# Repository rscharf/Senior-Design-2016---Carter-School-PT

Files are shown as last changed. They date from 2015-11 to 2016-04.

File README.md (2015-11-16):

# Senior Design 2016 - Carter School Physical Therapy
<br />
<center>

<br />
###BU ECE Senior Design Project
</center>
Creating an interactive wall-mounted display that helps with the physical therapy
program and individual student goals at the Carter School in Boston, MA.  The system consists of puzzle piece-shaped panels with LED numbers that light up when students move past each panel's active IR sensor.  With this system, we will help to foster a desire in the students to achieve new milestones in their own mobility as well as a deeper understanding of cause-and-effect and number sense.

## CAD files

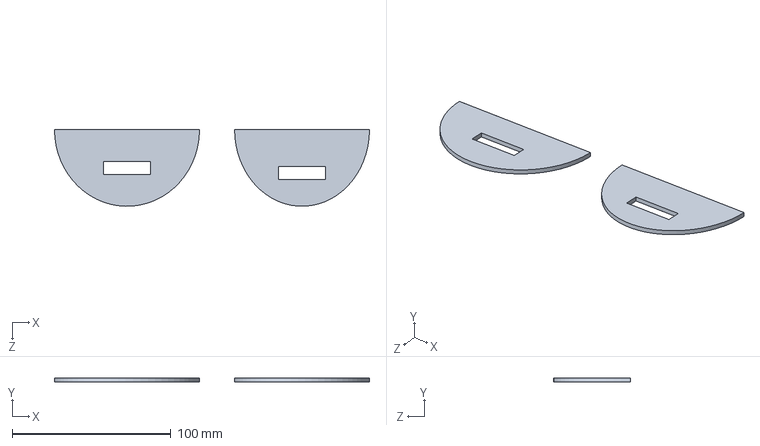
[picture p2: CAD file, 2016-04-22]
Solidworks/endbits.SLDPRT
198.7 x 2.54 x 48.3 mm

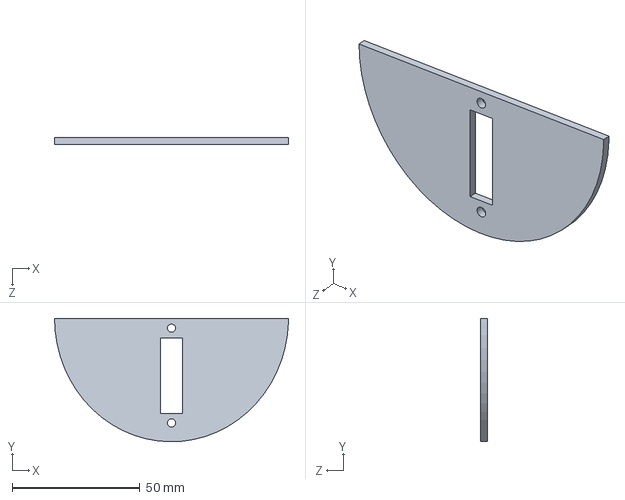
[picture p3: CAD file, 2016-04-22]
Solidworks/Sensor-end(acrylic).SLDPRT
91.4 x 48.3 x 2.54 mm

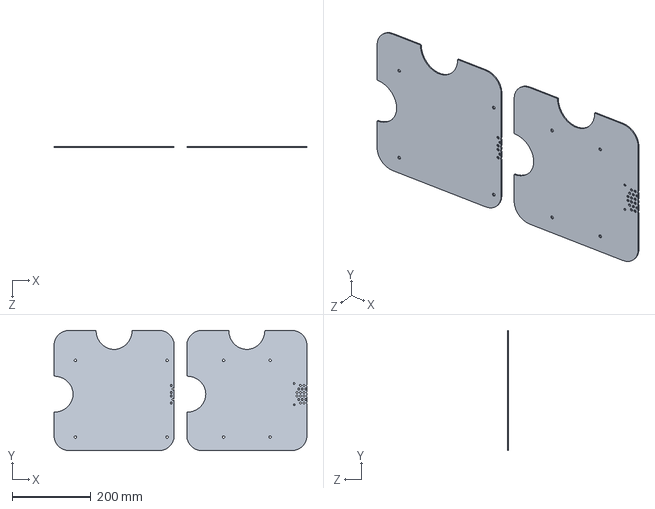
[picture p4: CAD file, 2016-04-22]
Solidworks/acrylic-screws.SLDPRT
641.3 x 304.8 x 2.54 mm

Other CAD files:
Solidworks/2fixed.SLDPRT
Solidworks/final.SLDPRT
Solidworks/sensor-end(film).SLDPRT
Solidworks/polyeth.SLDPRT
Solidworks/polyeth-outline.SLDDRW
Solidworks/sensor-end(film).SLDDRW

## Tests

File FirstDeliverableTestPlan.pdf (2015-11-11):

1

# Memo

To: | Professor Pisano, Professor Alshaykh, Professor Kia, Nithin Sivadas, Yue Zhang, Asher McGuffin
From: | Reva Scharf, Jian Tan, Jesse Leinbach, Austin Schiller, Maya Saint Germain, and Aidar Aidymbekov
Team: | 21
Date: | 11/10/2015
Subject: | Carter School Sensory Walk – First Deliverable Testing

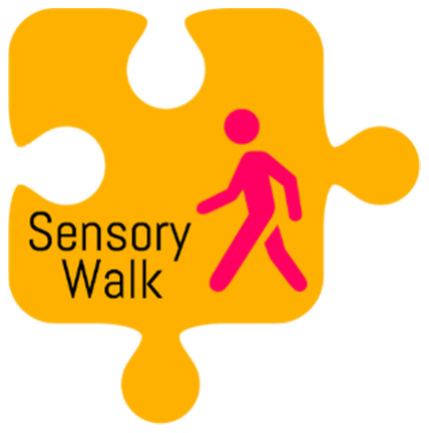
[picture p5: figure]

### 1.0 Panel Design: Hardware and Software

### 1.1 Description and Goal

As a proof of concept, we have a prototype of our sensor driven LEDs. The setup of each individual panel consists of one MSP430, one active IR sensor, and one LED driver circuit. The IR sensor emits IR, detects the reflected IR, and outputs an analog signal proportional to the intensity of the reflected IR detected. This analog signal is connected to a pulldown resistor as well as to a capacitor to ground in order to mitigate high frequency noise. The MSP430 then converts it into a digital signal with the use of an analog-to-digital converter (ADC) and averages the values in groups of five to further filter out noise. This averaged value is compared to a set threshold value, and if it is above the threshold, the on-board LED and P1.2 are set to high. P1.2 is connected to the base of our power BJT. This effectively turns it on, sending current to the emitter and powering a set of LEDs.
This system is the first iteration of the basic panel in our final modular design, which will consist of a group of similar panels that communicate with one another in order to detect movement along the school’s hallway. The communication between the MSP430s is implemented by connecting the two microcontrollers at their respective P1.5’s. Panel 0 sets a flag once it has been triggered. This flag is checked by Panel 1 on every cycle and it will only become active once Sensor 0 has been activated. This will help to prevent people or objects from interfering with the physical therapy session.

# Senior Design

## ENG EC 463

2

### 1.2 Procedure

Ensure both MSP430s are plugged in and power supply is supplying 5 volts. Connect the sensor output to an oscilloscope in order to show its effective range. Demonstrate two modes by loading each mode and then demonstrating. The first mode will allow both LEDs to turn on when an object is detected and off when nothing is detected. The second mode will show that the LEDs connected to Sensor 1 will not turn on until those of Sensor 0 turn on. Walk past the sensors, starting with sensor 0. Reset the system by pressing the on-board button (P1.3) of Sensor 0. Walk past Sensor 1 first, then Sensor 0, and then back to Sensor 1.

### 1.3 Verifiable Result

The MSP430 will constantly collect data from the sensor, convert it to a digital signal, store and average groups of five, and compare the average to a threshold. We can demonstrate the success of this process if the LEDs are activated by objects entering the sensor’s view. The distance from the person activating the system to the sensor will be on the order of 3 feet. This distance is more than acceptable to detect a student passing the sensor in a hallway. As the person gets closer, the oscilloscope will show how the sensor outputs a higher voltage. We will also show that once out of range completely, the voltage drops to zero. In the first mode, note that objects in range of 3 feet of either sensor will turn on their respective LEDs. If no objects are in range, the LEDs will turn off. In the second mode, note that Panel 1 is only activated after Panel 0 has been activated. Also note that pressing the on-board button (P1.3) of Panel 1 will reset only Panel 1, while pressing the button on Panel 0 resets both.

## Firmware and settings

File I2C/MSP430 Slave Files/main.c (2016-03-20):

/*** USCI slave library ********************************************************

In this file the usage of the USCI I2C slave code is shown. 
This code uses callback functions as an interface for the user. For each 
byte that is received or is to be transmitted the corresponding callback 
function is called by the USCI I2C function set.


PWM HELP:
http://coder-tronics.com/msp430-timer-pwm-tutorial/

Uli Kretzschmar
MSP430 Systems
Freising
*******************************************************************************/
#include "msp430.h"

#include "TI_USCI_I2C_slave.h"

void receive_cb(unsigned char receive);
void transmit_cb(unsigned char volatile *receive);
void set_address(unsigned char new_address);
void start_cb();

unsigned char set_add_flag = 0;
unsigned char TXData = 0 ;
unsigned char RXData = 0 ;
unsigned int byte_num = 0;
unsigned int state = 0;
unsigned char incomingData = 0;
unsigned char sensor_flag = 0;
unsigned int button_flag = 0;
unsigned int new_duty_cycle = 0;
//#define RESET_BUTT 8
/*** Global Variable ***/
int IncDec_PWM = 1;
// ADC variables
// Global variables that store the results (read from the debugger)
 volatile int latest_result;   // most recent result is stored in latest_result
 //volatile unsigned long conversion_count=0; //total number of conversions done
 volatile int adc_vals_before_ave = 0;
 volatile int adc_average = 0;
 volatile int adc_average_add = 0;
 volatile int adc_vals_array[5];
 volatile unsigned char last_button;
 volatile unsigned char last_button2;
 int blink_interval = 0;
 int blink_counter = 0;



// Declare variables in the information memory
#pragma DATA_SECTION(assigned_address,".infoD");
volatile const char assigned_address = 0x7f;

void main(void)
{

   TI_USCI_I2C_slaveinit(start_cb, transmit_cb, receive_cb, assigned_address); // init the slave
  _EINT();
  BCSCTL1 = CALBC1_16MHZ; 
  DCOCTL = CALDCO_16MHZ; //16 MHz calibration for clock
  init_adc();
  init_wdt();


  	P1DIR |= RED;                             // Set RED to output direction
    P1DIR |= BJT_OUT;
    P1DIR &= ~BUTTON;
    P1OUT &= ~BJT_OUT;

    P1OUT |= BUTTON;
    P1REN |= BUTTON;

    	/*** GPIO Set-Up ***/
        P1SEL |= BJT_OUT;					// BJT selected Timer0_A Out1 output

    	/*** Timer0_A Set-Up ***/
        TA0CCR0 |= 100;					// PWM period
        TA0CCR1 |= 0;					// TA0CCR1 PWM duty cycle
        TA0CCTL1 |= OUTMOD_7;			// TA0CCR1 output mode = reset/set
        TA0CTL |= TASSEL_2 + MC_1;		// SMCLK, Up Mode (Counts to TA0CCR0)


  _bis_SR_register(GIE+LPM0_bits);
}

void start_cb(){
  RXData = 0;
}

// Receive callback function. Values received are interpreted based on current state
// RPi should pass first the state and then the data and MSP will act accordingly
void receive_cb(unsigned char receive){
  byte_num++; //increases by 2 for every time this function is called
  if (byte_num == 2){ //first byte passed = state
	  state = receive;
  }
  else if (byte_num == 4){ //second byte passed is data (data is now stored in variable receive)
	  byte_num = 0;
  }

  if (byte_num == 0) //if data has just been received
  {
   switch(state) // Save new address to flash memory
   {
   	   case 0: //idle state
   		   P1OUT &= ~RED; //turn off on board LED?
   		   //P1OUT &= ~BJT_OUT; //turn off BJT LEDs
   		   TA0CCR1 = receive;
   		   break;
   	   case 1: // setting new address
   		   eraseD(); //Erase Data in D
   		   writeDword(receive, (char *) &assigned_address);//SET NEW ADDRESS in flash mem
   		   UCB0I2COA = assigned_address; // Set slave address register to address stored in flash mem
   		   break;
   	   case 2: //panel active and listening for sensor trigger
   		   break; //data received doesn't matter
   	   case 3: //idle state with lights activated - turn on LEDs
   		   //pi
   		   TA0CCR1 = receive; //set new duty cycle to value of brightness preference
   		   P1OUT |= BJT_OUT; //Turn on BJT LEDs
   		   P1OUT |= RED; //Turn on on-board LED
   		   sensor_flag = 0;
   		   break;
   	   case 4:
   		   break; //data received doesn't matter
   	   default:
   		   break;
   }

    }

}

void transmit_cb(unsigned char volatile *byte){
	 switch(state) // Save new address to flash memory
	   {
	   	   case 0: //idle state
	   		   *byte = 0;
	   		   P1OUT &= ~BJT_OUT; //Turn off BJT LEDs
	   		   P1OUT &= ~RED; //Turn off on-board LED
	   		   break;
	   	   case 1: // setting new address
	   		   *byte = assigned_address; //Send slave's address to master (retreived from flash mem)
	   		   state = 0; //reset to Idle state after new address is sent to master
	   		   break;
	   	   case 2: //panel active and listening for sensor trigger
	   		   if ((sensor_flag == 1))
	   		   {
    			*byte = 1;
    			sensor_flag = 0;
    			button_flag = 0;
	   			//state = 3; //Dont enter state 3 until told by RPI..later
	   		   }
	   		   else *byte = 0;
	   		   break; //data received doesn't matter
	   	   case 3: //idle state with lights activated, no action in transmit necessary
	   		   *byte = 0;
	   		   break;
	   	   default:
	   		   *byte = 0;
	   		   break;
	   }
}

/*
 * The ADC handler is invoked when a conversion is complete.
 * Its action here is to simply store the result in memory.
 */
 void interrupt adc_handler(){
	 latest_result=ADC10MEM;   // store the answer
 }
 ISR_VECTOR(adc_handler, ".int05")




// ===== Watchdog Timer Interrupt Handler =====
interrupt void WDT_interval_handler(){

{
						ADC10CTL0 |= ADC10SC;  // trigger a conversion
						//Reset button. Should this only be accessible from state 2/3?
						//button handling - for now this button acts as a sensor+
						unsigned char b;
						b= (P1IN & BUTTON);  // read the BUTTON bit
						if (last_button && (b==0))
						{ // has the button bit gone from high to low
						  //turn off LEDs and go back to idle state
							//P1OUT ^= RED;
							P1OUT &= ~RED; //turn off on board LED?
							P1OUT &= ~BJT_OUT; //turn off BJT LEDs
							button_flag = 1;
							state = 0;
						}
						last_button=b;    // remember button reading for next time.


						int j;
						for (j=0; j<5; j++)
						{
							adc_average_add = adc_average_add + adc_vals_array[j];
						}
						adc_average = adc_average_add/5;
						adc_average_add = 0;

						if ((adc_average > IR_THRESHOLD) && (state == 2))
						{
							//P1OUT |= RED;
							sensor_flag = 1; //indicate sensor trigger
						}

						if (adc_vals_before_ave == 5)
						{
							adc_vals_before_ave = 0;
						}
						else
						{
							adc_vals_array[adc_vals_before_ave] = latest_result;
							adc_vals_before_ave++;
						}

	 	 }

}

ISR_VECTOR(WDT_interval_handler, ".int10")

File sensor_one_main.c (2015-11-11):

/* 10-30-13
 * This is an example of using the ADC to convert a single
 * analog input. The external input is to ADC10 channel A4.
 * This version triggers a conversion with regular WDT interrupts and
 * uses the ADC10 interrupt to copy the converted value to a variable in memory.
*/

#include "msp430g2553.h"

// Define bit masks for ADC pin and channel used as P1.4
#define ADC_INPUT_BIT_MASK 0x10
#define ADC_INCH INCH_4
#define BJT_OUT	4
#define COM_IN 0x20
#define RESET_BUTT 8

#define IR_THRESHOLD	70

 /* declarations of functions defined later */
 void init_adc(void);
 void init_wdt(void);

// =======ADC Initialization and Interrupt Handler========

// Global variables that store the results (read from the debugger)
 volatile int latest_result;   // most recent result is stored in latest_result
 //volatile unsigned long conversion_count=0; //total number of conversions done
 volatile int adc_vals_before_ave = 0;
 volatile int adc_average = 0;
 volatile int adc_average_add = 0;
 volatile int adc_vals_array[5];
 volatile unsigned char last_button;

/*
 * The ADC handler is invoked when a conversion is complete.
 * Its action here is to simply store the result in memory.
 */
 void interrupt adc_handler(){
	 latest_result=ADC10MEM;   // store the answer
 }
 ISR_VECTOR(adc_handler, ".int05")

// Initialization of the ADC
void init_adc(){
  ADC10CTL1= ADC_INCH	//input channel 4
 			  +SHS_0 //use ADC10SC bit to trigger sampling
 			  +ADC10DIV_4 // ADC10 clock/5
 			  +ADC10SSEL_0 // Clock Source=ADC10OSC
 			  +CONSEQ_0; // single channel, single conversion
 			  ;
  ADC10AE0=ADC_INPUT_BIT_MASK; // enable A4 analog input
  ADC10CTL0= SREF_0	//reference voltages are Vss and Vcc
 	          +ADC10SHT_3 //64 ADC10 Clocks for sample and hold time (slowest)
 	          +ADC10ON	//turn on ADC10
 	          +ENC		//enable (but not yet start) conversions
 	          +ADC10IE  //enable interrupts
 	          ;
}


 // ===== Watchdog Timer Interrupt Handler =====
interrupt void WDT_interval_handler(){
		ADC10CTL0 |= ADC10SC;  // trigger a conversion

		//button handling
				unsigned char b;
				b= (P1IN & RESET_BUTT);  // read the BUTTON bit
				if (last_button && (b==0))
				{ // has the button bit gone from high to low
				  //turn off LEDs and reset COM_OUT to low
					P1OUT &= ~0x01;
					P1OUT &= ~BJT_OUT;
				}
				last_button=b;    // remember button reading for next time.

		unsigned char com_in_val;
		com_in_val = (P1IN & COM_IN);
		//com_in_last = com_in_val;

		if (com_in_val == 0)
		{
			P1OUT &= ~0x01;
			P1OUT &= ~BJT_OUT;
		}

		int j;
		for (j=0; j<5; j++)
		{
			adc_average_add = adc_average_add + adc_vals_array[j];
		}
		adc_average = adc_average_add/5;
		adc_average_add = 0;

		if ((adc_average > IR_THRESHOLD) && (com_in_val !=0))
		{
			P1OUT |= 0x01;
			P1OUT |= BJT_OUT;
		}

		if (adc_vals_before_ave == 5)
		{
			adc_vals_before_ave = 0;
		}
		else
		{
			adc_vals_array[adc_vals_before_ave] = latest_result;
			adc_vals_before_ave++;
		}

}
ISR_VECTOR(WDT_interval_handler, ".int10")

 void init_wdt(){
	// setup the watchdog timer as an interval timer
  	WDTCTL =(WDTPW +		// (bits 15-8) password
     	                   	// bit 7=0 => watchdog timer on
       	                 	// bit 6=0 => NMI on rising edge (not used here)
                        	// bit 5=0 => RST/NMI pin does a reset (not used here)
           	 WDTTMSEL +     // (bit 4) select interval timer mode
  		     WDTCNTCL  		// (bit 3) clear watchdog timer counter
  		                	// bit 2=0 => SMCLK is the source
  		                	// bits 1-0 = 00 => source/32K
 			 );
     IE1 |= WDTIE;			// enable the WDT interrupt (in the system interrupt register IE1)
}

/*
 * The main program just initializes everything and leaves the action to
 * the interrupt handlers!
 */

void main(){

	WDTCTL = WDTPW + WDTHOLD;       // Stop watchdog timer
	BCSCTL1 = CALBC1_8MHZ;			// 8Mhz calibration for clock
  	DCOCTL  = CALDCO_8MHZ;

  	init_adc();
  	init_wdt();

  	P1DIR |= 0x01;
  	P1DIR |= BJT_OUT;
  	P1DIR &= ~COM_IN; //set p1.5 as input from sensor_zero
  	P1DIR &= ~RESET_BUTT;

  	P1OUT |= RESET_BUTT;
  	P1REN |= RESET_BUTT;

	_bis_SR_register(GIE+LPM0_bits);
}

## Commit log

2015-11-03 Imported preliminary code for sensor input conversion through ADC and output to onboard LED and an additional pin
2015-11-06 Preliminary msp 430 code for two msps & IR sensors
    sensor_zero code controls first msp430 and will send a high signal to
    second msp430 once the first IR sensor is triggered. The second IR
    sensor will not cause LEDs to turn on until a high signal is received
    from first msp. The second msp430 works with the sensor_one code
2015-11-11 Fix minor issue with sensor one code
    [sensor_one_main.c]
2015-12-17 Initial I2C stuff, familiarizing with TI code
2016-01-21 I2C updated, mostly TI I2C library files
2016-01-26 Initial touchscreen GUI code
    GUI with logo and one button
2016-01-27 Edited test GUI for I2C to communicated with two MSP430s
    Implemented two buttons to send a signal to individual MSP430s over
    I2C. When the MSP gets the signal, it toggles the on board LED. Then
    the Pi asks to read from the MSP and reads the MSP’s address from the
    MSP. The address is displayed on the button that was pushed initially.
2016-01-27 Working Slave Files
    Slave files - Rasp Pi can recognize the attached slave device, which has
    an address defined by the slave itself
2016-01-27 I2C Slave Files 1.27.16
    MSP slaves can send and receive data successfully from the RPI
2016-01-28 New code that implements home screen with four buttons
    new multi-screen code. no transitions. home screen has options to go
    start a run, manage profiles, go to settings, and exit. the first
    three direct to new screens, the exit button currently does not have
    functionality.
2016-02-03 Screen code with I2C code
    currently not working with MSP430s, problem believed to be with MSP430
    C code
    [screen.py]
2016-02-11 Beginning of profile generation, clocking for user runs
    Added code to save user profiles to profiles.txt file. Sample
    profiles.txt added. Created a clock that runs startRun function on a
    set interval. Set to 1 second for testing. Will change granularity
    when actually working with I2C. Currently just updates the screen
    label by incrementing the number by 1.
2016-02-21 Fixed ListView bug for select user for run
    committed functioning code for start user run screen. partially
    functioning code for edit and delete screens. (Committed in case I
    break anything…)
    [screen.py]
2016-02-21 Implemented delete profile functionality
    Delete profile functionality implemented with “are you sure” screen
2016-02-22 screen python code with I2C partially functioning to MSP430s for user runs
    screen.kv does not change from most recent commits
2016-02-22 Sensor Circuit Integrated
    Sensor circuit and ADC code has been added to the slave function. Slaves
    can now be initialized with their address, and participate in a practice
    run. Rasp pi tells the first panel it is active, and once its sensor is
    triggered, second panel becomes active and waits for sensor trigger.
2016-02-24 modified GUI functionality, added rudimentary sound to I2C functionality
2016-02-25 Updated States
    States 0, 1, 2, and 3 are more or less finished.
    State 0: Idle, lights off, sensor off
    State 1: Initialization, receive new address and then pass it back
    State 2: Sensor active, lights off - until sensor has been triggered
    State 3: Sensor off, lights on - until run has been ended
2016-02-28 Added (hopefully) final screens to UI
    save data screens and buttons added; currently no functionality behind
    them.
2016-03-03 scripts added that implement reset button functionality
    buttonlook.py is the button handler that will be running in the
    background starting at boot looking for button pushes. run.sh is how
    the UI will be started on boot and allows it to be restarted when the
    button kills the currently running (or frozen) UI
2016-03-04 Untested (but most likely working) panel replacement screen functionality
    I’m stupid and had to rewrite this because I never committed it and I
    overwrote it on the Pi. Let’s never do that again.
    [screen.py]
2016-03-08 Added timing between runs and save functionality
    Now all runs have timing between panels and all data can be saved to a
    formatted Excel spreadsheet. Each user has their own sheet within the
    SensoryWalk.xlsx worksheet. The sheet for each user is created on
    their first run.
2016-03-20 PWM Slave Files
    Slave files have been updated to use pwm on bjt output for variable
    light output
2016-03-20 modified for passing brightness values from user profiles to MSP430s for PWM
    now changing brightness of LEDs should be in effect
2016-03-31 debug and additions
    1. took three large functions and added them to separate file “fn.py”
    to separate code from the VERY LARGE file that was forming
    2. fixed some logic bugs: user with no name can’t be created
    3. added UI design for export excel data functionality
    4. added password protection for PanelReplacementScreen (still needs to
    be added for InitialPanelConfigScreen)
    5. brightness additions to have brightness displayed on panel 0 LEDs
    during profile creation and editing
    [fn.py, screen.py]
2016-04-01 put all instances of writing to or reading from the I2C bus in a try block
2016-04-03 Implemented export excel spreadsheet functionality
    export.sh script mounts the flash drive, removes any existing
    spreadsheet, copies over the new one, and unmount the flash drive.
    fn.py changed to include imports
    screen.kv changed to add functionality
    screen.py changed to add exportButt and backButt functions
2016-04-11 english files created
    cut up english files using audacity. amplified the files and got rid
    of noise
2016-04-13 Revert "Cleaned up slave main.c"
    This reverts commit 21b570d514cd8ce3b57d61b1734d1ac2445d3443.
    [main.c]
2016-04-14 removed InitialPanelConfigScreen
    it was deemed unnecessary since the same functionality could be
    achieved with the panel replacement screen
    [screen.py]
2016-04-14 small change regarding logic of timings
    when excelDataSave function was moved to fn.py, the timings array was
    no longer in the correct scope. Had to change so it was passed as a
    parameter of the function.
    [fn.py, screen.py]
2016-04-21 error handling for panel replacement -- TEST ME ON PI
    if no panel number was selected and it tried to convert ‘#’ into an
    int, there was an error that caused the UI to crash. this is handling
    for that, but it still needs to be tested briefly.
    [screen.py]
2016-04-22 Solidworks Models
    All Solidworks models used in creating the acrylic panels, polethylene film, and polycarbonate boxes.
    [2fixed.SLDPRT, Sensor-end(acrylic).SLDPRT, acrylic-screws.SLDPRT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]
